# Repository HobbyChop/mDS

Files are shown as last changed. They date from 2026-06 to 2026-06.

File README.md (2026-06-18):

<table>
  <tr>
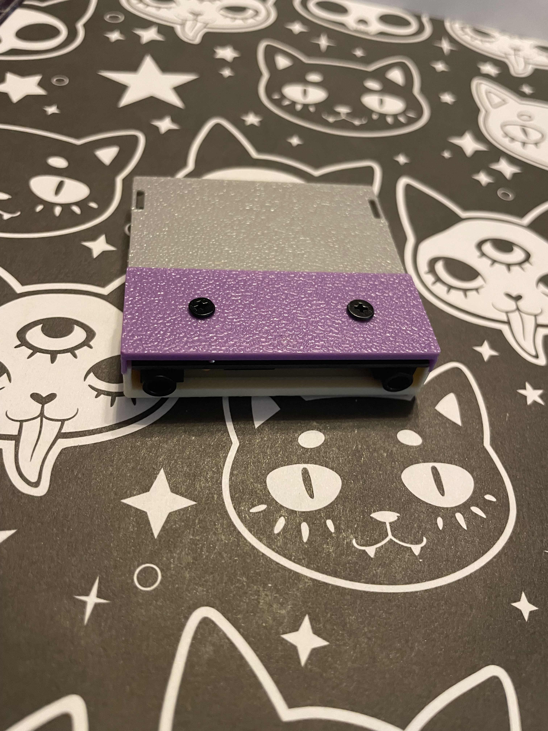
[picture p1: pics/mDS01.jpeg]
    <td align="center"><br></td>
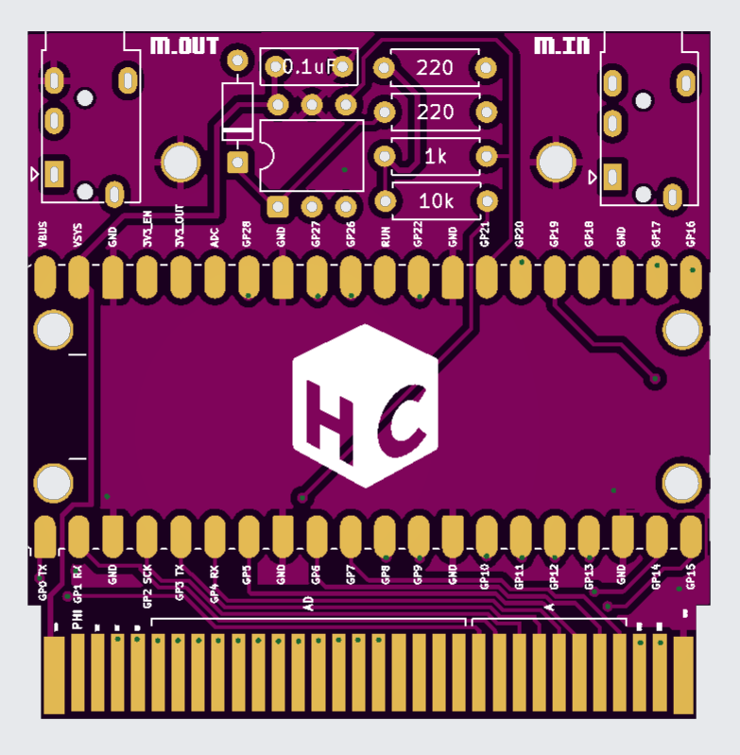
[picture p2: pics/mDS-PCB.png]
    <td align="center"><br></td>
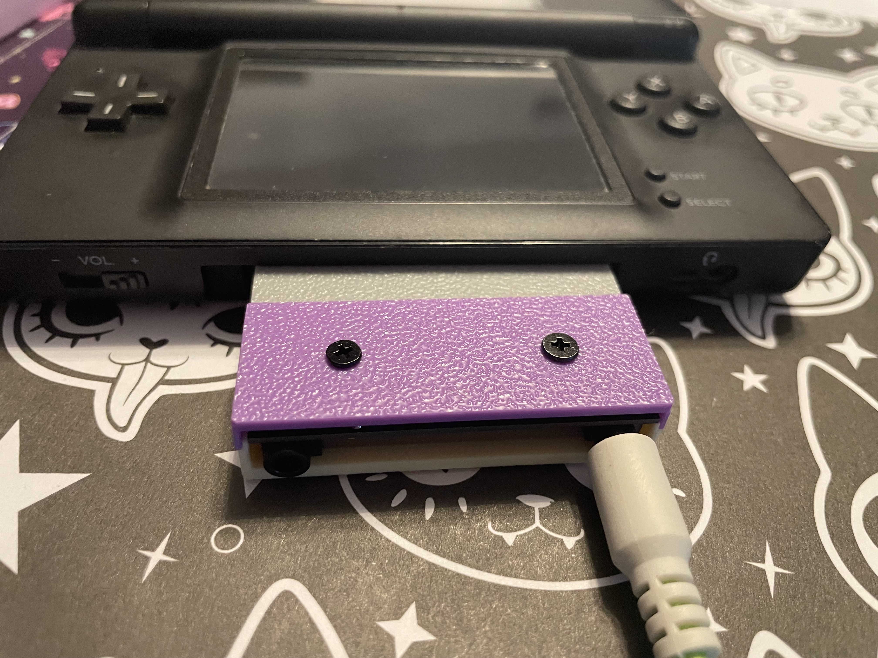
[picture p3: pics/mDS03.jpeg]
    <td align="center"><br></td>
  </tr>
</table>

# mDS - DS slot-2 MIDI cartridge

**mDS** is a Nintendo DS / DS Lite **slot-2 (GBA Game Pak) MIDI interface**
built on an RP2040. It bridges hardware MIDI into the DS over the slot-2
SRAM bus so a DS app can be a MIDI synth. The DS is the synth; the cart is
the interface - see the [sDS synth app](https://github.com/HobbyChop/sDS), the
baseline ROM that runs on it.

> One firmware, two jobs: mDS speaks the mDS `"STDS"` protocol at **version
> 2** (MIDI clock + a MIDI event ring), so the same cart drives both the
> sDS synth *and* clock-sync apps (e.g. stutter-ds) with no changes.

## Specs

| | |
|---|---|
| **MCU** | RP2040 - dual Cortex-M0+ @ 133 MHz, 264 KB SRAM (Raspberry Pi Pico module, 2 MB flash) |
| **Host interface** | GBA slot-2 SRAM region `0x0A000000`, 4 KB window (12-bit address), serviced by a PIO state machine |
| **MIDI IN** | 31250 baud UART, opto-isolated (6N138 / H11L1) |
| **MIDI OUT** | 31250 baud UART, 2x220 ohm -> TRS/DIN-5 |
| **Indicator** | onboard green LED (GPIO25): status + MIDI activity via PWM |
| **Power** | slot-2 3.3 V rail, no level shifting; 22 uF reservoir cap on VSYS |
| **Programming** | USB BOOTSEL (drag-and-drop UF2); SWD pads optional |
| **Compatibility** | DS / DS Lite only (DSi+ dropped slot-2) |

## Slot-2 bus (pin summary)

In the SRAM region the bus is **not** multiplexed: low address on A0..A11,
data returned on A16..A23 during `/RD`.

| Slot-2 signal | RP2040 GPIO | Dir | Role |
|---|---|---|---|
| A0..A7 | GPIO8..15 | in  | address low |
| A8..A11  | GPIO22, 26, 27, 28 | in  | address high (4 KB window) |
| A16..A23 | GPIO0..7 | out | data bus (driven during `/RD`) |
| /CS2 | GPIO16 | in  | SRAM chip select |
| /RD | GPIO17 | in  | read strobe |
| /WR | GPIO18 | in  | write strobe (unused) |
| /IRQ | GPIO19 | out | optional cart->DS line |
| MIDI TX  | GPIO20 | out | DIN/TRS OUT |
| MIDI RX  | GPIO21 | in  | opto IN |

## Firmware

- **core 1** runs a PIO slot-2 bus servicer (pinned to SRAM for constant-time
  serves): it answers DS reads of the SRAM window from a mirrored state struct,
  and emits MIDI OUT on trigger-reads - fixed transport at `0xE0..0xE3` plus a
  general byte sender at `0xC0..0xDF` (full notes / CC / pitch-bend / etc.).
- **core 0** parses MIDI IN (real-time clock/transport - a clock mirror;
  channel-voice notes/CC - a 16-entry event ring the DS polls) and drives
  the status LED.

### LED

| State | LED |
|---|---|
| powered, alive, no DS reading | dim slow breathe |
| a DS is linked (reading the bus) | steady glow |
| MIDI note/CC arrives | bright flash |
| MIDI clock running (transport play) | heartbeat pulse on the beat |

## Development specification

This is the most technical part of the README: how the cart works under the
hood, and how to talk to it from your own DS program. 

### How the DS and the cart talk

The cart pretends to be a small block of memory that the DS can peek at through
the Game Pak slot - picture a little **notice board**. The cart keeps the board
updated with the latest MIDI info, and the DS just keeps re-reading it.

The catch: on a real DS the slot can be **read but not reliably written**. So
the DS can look at the board, but it can't write a reply back onto it. When the
DS needs to send something *to* the cart, it instead "reads" a few special spots
on the board; the cart notices which spot was read and treats that as a command
- like buttons that do nothing except ring a bell on the cart's side (see
*Outgoing MIDI* below).

> **For programmers:** the board sits at `0x0A000000`. Open the slot with
> `gbacartOpen()` and pick the **slowest** read speed (`GBA_WAIT_SRAM_18`) so the
> cart has time to answer each read (~540 ns). Read **one byte at a time** - a
> wider read just repeats the same byte (a slot quirk). Only the first **256
> bytes** matter; reads past that wrap back to the start.

### What's on the board (layout)

An ID tag so the DS can confirm a real cart is present, some live clock and
tempo info, then a 16-slot **inbox** of recent MIDI messages. Exact layout for
coders:

| Offset | Field | Type | What it is |
|---|---|---|---|
| `0x00` | `magic` | char[4] | the tag `"STDS"` (confirms a real cart) |
| `0x04` | `version` | u8 | protocol version (`2`) |
| `0x05` | `flags` | u8 | bit0 = clock running, bit1 = transport playing |
| `0x06` | `_pad` | u8[2] | spacing |
| `0x08` | `tick_counter` | u32 | MIDI clock tick count (24 per beat) |
| `0x0C` | `bpm_q8` | u32 | tempo in BPM (fixed-point, x256) |
| `0x10` | `micros` | u32 | cart uptime in microseconds (proves it's alive) |
| `0x14` | `song_pos_16ths` | u16 | song position (in 16th notes) |
| `0x16` | `midi_write_head` | u8 | inbox: newest-slot counter (cart writes it) |
| `0x17` | `midi_read_head` | u8 | inbox: DS read position (advisory) |
| `0x18..0x57` | `midi_ring[16]` | 4B ea. | the 16-slot MIDI inbox |
| `0x58..0xFD` | `_reserved` | | unused (reads back 0) |
| `0xC0..0xE3` | doorbell addresses | | reading these sends MIDI out (see below) |

Each value is written by the cart and only read by the DS, so read one field at
a time and you always get a clean value.

### Incoming MIDI: the inbox (cart -> DS)

When MIDI arrives at the cart's IN jack, the cart drops each note or control
change into the next inbox slot and bumps a "newest" counter. The DS watches
that counter and grabs whatever it hasn't seen. The cart always finishes writing
a slot *before* bumping the counter, so the DS never catches a half-written
message. Each slot is 4 bytes:

| Byte | Meaning |
|---|---|
| 0 | message type (high half) + channel (low half) |
| 1 | first data byte (note number / CC number / ...) |
| 2 | second data byte (velocity / value / ...; 0 if unused) |
| 3 | timestamp (low byte of the clock tick) |

(Clock, start, stop, and tempo arrive separately and update the clock/tempo
fields at the top of the board, not the inbox.)

### Outgoing MIDI: the doorbell trick (DS -> cart -> OUT)

Because the DS can't write to the cart, sending MIDI *out* runs in reverse: the
DS **reads** special addresses, and the cart turns each one into a byte sent out
the MIDI OUT jack. The read returns nothing useful (just a zero) - the act of
reading *is* the message. Four addresses are hard-wired to the transport bytes,
and a range lets the DS send *any* byte:

| Read this address | What the cart does |
|---|---|
| `0xE0` / `0xE1` / `0xE2` / `0xE3` | send clock / start / stop / continue (one read each) |
| `0xC0..0xCF` | remember the high half of the next byte |
| `0xD0..0xDF` | send a byte = (that high half) + (this address's low half) |

To send any byte (notes, CC, pitch-bend, anything) the DS splits it into two
halves and reads one address for each: `0xC0 | (B>>4)` then `0xD0 | (B&0xF)`.
It's a little indirect but very fast - about 2 us per byte, far quicker than
MIDI's own wire speed, so nothing backs up. The DS-side helpers do all this for
you: `synth_cart_note_on/off/cc`, `synth_cart_midi_send`, and
`synth_cart_midi_send_byte`.

### Speed and chip layout

The Pico has two CPU cores, split cleanly: **one core does nothing but answer
the DS's reads** the instant they arrive (its code even runs from RAM so nothing
can slow it down), and **the other** handles incoming MIDI and the status light.
It runs at the stock 125 MHz - no overclock, to stay gentle on the slot's power.
MIDI is a slow 1980s standard, and the cart answers reads hundreds of times
faster than MIDI data arrives, so it never struggles to keep up.

### Limits

Great for MIDI and clock, not a channel for bulk data. The link is read-only
(the doorbell trick is the only way back), one byte per read, and 256 bytes of
shared space - plenty for MIDI (which only needs ~3 KB/s), but the hard ceiling
is around 1 MB/s, so it isn't a general-purpose data pipe.

### Writing your own DS program for it

1. Open the slot (`gbacartOpen()`) and set the slow read speed
   (`GBA_WAIT_SRAM_18`).
2. Check the ID tag: `"STDS"` at the start, version `2` right after.
3. Each frame, read the "newest" counter and pull any new inbox messages.
4. To send MIDI out, call the helper functions - and don't read the doorbell
   addresses (`0xC0..0xE3`) by accident, since reading them sends MIDI.
5. Working example: the sDS app.

## Build & flash

Uses the Raspberry Pi Pico SDK. Native (Windows) toolchain recipe:

```
cd rp2040
cmake -S . -B build -G "MinGW Makefiles" -DPICO_BOARD=pico -DPICO_SDK_PATH=C:/pico-sdk
cmake --build build -j
```

(Or `-G "Unix Makefiles"` on Linux/macOS with `PICO_SDK_PATH` exported.)
Output: **`build/mDS_v12.uf2`** (the artifact name is versioned via the target's
`OUTPUT_NAME` in `CMakeLists.txt`). Hold **BOOTSEL**, plug USB, copy the UF2
onto the `RPI-RP2` drive.

## License

Licensed under **[CC BY-NC-SA 4.0](../LICENSE)** (Attribution-NonCommercial-
ShareAlike). You may build, modify, and share your own mDS for
**non-commercial** use, with attribution and under the same license;
**selling mDS units or derivatives is not permitted**.

**Intent:** use the mDS however you like, including to make and **sell
music** (the license does not cover what you create with it). The
restriction is only on dealing in the device/design itself: no selling
mDS units or kits, no manufacturing for sale, no selling modified
firmware/hardware.

The "mDS" / "sDS" names are reserved by the author (trademark is separate
from this copyright license). For commercial use, contact the author.

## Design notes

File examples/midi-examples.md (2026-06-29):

# mDS cart -- DS-side MIDI examples

Minimal, copy-pasteable C for talking to the **mDS** slot-2 MIDI cart from a
Nintendo DS homebrew (devkitARM + libnds/calico). It covers **sending** and
**receiving** MIDI notes, CC, and clock/transport.

The cart exposes a small memory-mapped struct at the slot-2 base. Two quirks to
know up front:

1. **Read in single bytes.** The slot-2 SRAM region replicates a byte across a
   wider load, so a 32-bit read must be done as four `LDRB`s, not one `LDR`.
2. **Output is conveyed by *reads*, not writes** (the cart can't be written
   reliably). Each outgoing byte is two reads: a read of `0xC0|hi` latches the
   high nibble, then a read of `0xD0|lo` makes the cart emit `(hi<<4)|lo` on its
   UART TX.

---

## 1. Register map & low-level access

```c
#include <nds.h>
#include <calico/nds/gbacart.h>   // gbacartOpen / gbacartSetTiming

#define MDS_BASE        0x0A000000u   // slot-2 base

// offsets into the cart's mirrored sync struct
#define MDS_MAGIC       0x00          // "STDS" (4 bytes) when present
#define MDS_FLAGS       0x05          // bit1 = transport playing
#define MDS_TICK        0x08          // u32, monotonic 24-PPQ clock tick
#define MDS_BPM_Q8      0x0C          // u32, BPM in Q8.8 fixed point
#define MDS_WRITE_HEAD  0x16          // cart's ring write cursor (u8)
#define MDS_READ_HEAD   0x17          // our consume cursor (u8)
#define MDS_RING        0x18          // 16 entries x 4 bytes: status, d1, d2, tick_lo
#define MDS_RING_LEN    16
#define MDS_RING_ENTRY  4

#define MDS_TX_HI       0xC0          // read 0xC0|hi  -> latch high nibble
#define MDS_TX_LO       0xD0          // read 0xD0|lo  -> emit (hi<<4)|lo on UART

#define MDS_FLAG_PLAY   (1u << 1)

// A single-byte read is correct; only wide loads hit the replication quirk.
static inline u8 mds_rd8(u32 off) {
    return *(volatile u8 *)(MDS_BASE + off);
}

// 32-bit read as four explicit LDRBs (so the compiler can't fold them to one LDR).
static u32 mds_rd32(u32 off) {
    u32 base = MDS_BASE + off, b0, b1, b2, b3;
    __asm__ __volatile__(
        "ldrb %0,[%4,#0]\n ldrb %1,[%4,#1]\n ldrb %2,[%4,#2]\n ldrb %3,[%4,#3]\n"
        : "=&l"(b0), "=&l"(b1), "=&l"(b2), "=&l"(b3) : "l"(base) : "memory");
    return b0 | (b1 << 8) | (b2 << 16) | (b3 << 24);
}
```

---

## 2. Detect / open the cart

```c
static int   s_active   = 0;
static u8    s_read_head = 0;

// Open slot-2, set timing, and verify the cart magic. Safe to call again to
// re-probe. Returns true if an mDS cart is present.
bool mds_open(void) {
    if (!gbacartOpen()) { s_active = 0; return false; }   // claim slot-2 + MPU
    gbacartSetTiming(GBA_WAIT_SRAM_MASK, GBA_WAIT_SRAM_18);

    // The open/timing hand-off is async, so retry the magic read a few times.
    for (int i = 0; i < 16; ++i) {
        if (mds_rd8(MDS_MAGIC+0)=='S' && mds_rd8(MDS_MAGIC+1)=='T' &&
            mds_rd8(MDS_MAGIC+2)=='D' && mds_rd8(MDS_MAGIC+3)=='S') {
            s_active    = 1;
            s_read_head = mds_rd8(MDS_WRITE_HEAD) % MDS_RING_LEN;   // start synced
            return true;
        }
        swiDelay(2000);
    }
    gbacartClose();
    s_active = 0;
    return false;
}

bool mds_present(void) { return s_active != 0; }
```

> Tip: don't touch slot-2 before `mds_open()` -- a raw read on some flashcarts
> before the cart is claimed can wedge them. Probe a couple of frames into boot.

---

## 3. Send MIDI OUT (notes, CC, raw bytes)

```c
// One raw byte out (use this for realtime bytes: clock 0xF8, start 0xFA, stop 0xFC).
void mds_send_byte(u8 b) {
    if (!s_active) return;
    (void)mds_rd8((u32)MDS_TX_HI | (u32)(b >> 4));     // latch high nibble
    (void)mds_rd8((u32)MDS_TX_LO | (u32)(b & 0x0F));   // low nibble -> cart emits b
}

// One channel-voice message (status 0x80..0xEF).
void mds_send(u8 status, u8 d1, u8 d2) {
    if (!s_active || status < 0x80 || status >= 0xF0) return;
    mds_send_byte(status);
    mds_send_byte(d1 & 0x7F);
    mds_send_byte(d2 & 0x7F);
}

static inline void mds_note_on (u8 ch, u8 note, u8 vel) { mds_send(0x90 | (ch & 0xF), note, vel); }
static inline void mds_note_off(u8 ch, u8 note, u8 vel) { mds_send(0x80 | (ch & 0xF), note, vel); }
static inline void mds_cc      (u8 ch, u8 num,  u8 val) { mds_send(0xB0 | (ch & 0xF), num,  val); }

// Example: play middle C on channel 1 for one beat, then release.
void example_play_note(void) {
    mds_note_on(0, 60, 100);     // ch 1 (0-based), note 60, velocity 100
    // ... hold for a beat ...
    mds_note_off(0, 60, 0);
}
```

---

## 4. Receive MIDI IN (drain the event ring)

External gear -> cart UART RX -> 16-entry ring -> your DS. Drain it every frame.

```c
// Pop one received channel-voice event. Returns true and fills out-params when
// one was waiting; false when the ring is drained. Skips torn/empty slots.
bool mds_recv(u8 *status, u8 *d1, u8 *d2) {
    if (!s_active) return false;
    u8 wh = mds_rd8(MDS_WRITE_HEAD) % MDS_RING_LEN;
    int guard = 0;
    while (s_read_head != wh && guard++ < MDS_RING_LEN) {
        u32 e = MDS_RING + (u32)s_read_head * MDS_RING_ENTRY;
        u8 s = mds_rd8(e+0), a = mds_rd8(e+1), b = mds_rd8(e+2);   // [3] = tick_lo
        s_read_head = (s_read_head + 1) % MDS_RING_LEN;
        if (s & 0x80) {                  // valid status byte = a real event
            if (status) *status = s;
            if (d1) *d1 = a;
            if (d2) *d2 = b;
            return true;
        }
    }
    return false;
}

// Example: consume everything received this frame.
void example_read_input(void) {
    u8 st, d1, d2;
    while (mds_recv(&st, &d1, &d2)) {
        u8 type = st & 0xF0, ch = st & 0x0F;
        if      (type == 0x90 && d2 > 0) { /* note on : note=d1 vel=d2 ch=ch */ }
        else if (type == 0x80 || (type == 0x90 && d2 == 0)) { /* note off */ }
        else if (type == 0xB0) { /* control change: cc=d1 val=d2 */ }
    }
}
```

---

## 5. Clock & transport

### Reading an incoming clock (slave)

```c
int  mds_bpm(void) {                          // 0 if no clock
    if (!s_active) return 0;
    u32 q8 = mds_rd32(MDS_BPM_Q8);
    if (q8 < (20u<<8) || q8 > (300u<<8)) return 0;   // sanity gate
    return (int)((q8 + 128u) >> 8);                  // Q8 -> nearest BPM
}

u32  mds_tick(void) { return s_active ? mds_rd32(MDS_TICK) : 0; }   // 24 PPQ
bool mds_playing(void) { return s_active && (mds_rd8(MDS_FLAGS) & MDS_FLAG_PLAY); }

// Example: derive bar/beat and step a 16-step sequencer off the incoming clock.
// The tick is monotonic 24-PPQ; the host zeroes it on transport Start.
void example_follow_clock(void) {
    if (!mds_playing()) return;
    u32 t    = mds_tick();
    int beat = (t / 24) % 4;           // 24 ticks per quarter note
    int step = (t / 6) % 16;           // 6 ticks = 1/16 note -> 16 steps/bar
    (void)beat; (void)step;            // fire your step here when it changes
}
```

### Being the master (send clock out)

MIDI clock is 24 pulses per quarter note. **For tight timing, drive this from a
hardware-timer IRQ** (≈1–2 kHz) rather than the 60 Hz VBlank loop -- emitting one
F8 per frame bunches pulses on frame boundaries (up to ~16 ms jitter).

```c
// Call at your tick cadence (ideally a timer ISR). Sends 24 F8 per quarter.
void mds_clock_pulse(void) { mds_send_byte(0xF8); }   // realtime clock
void mds_transport_start(void) { mds_send_byte(0xFA); }   // slaves reset to bar 1 + run
void mds_transport_stop (void) { mds_send_byte(0xFC); }   // slaves halt

// Phase-accumulator example for a VBlank-loop master (carries the remainder so
// there's no long-term drift; jitter is frame-granular -- use a timer for tight).
static int s_acc = 0;
void example_emit_clock_per_frame(int bpm) {   // call once per 60 Hz frame
    s_acc += bpm;                               // 1 quarter = 3600 units @ 60fps
    while (s_acc >= 150) { mds_clock_pulse(); s_acc -= 150; }   // 3600/24 = 150
}
```

---

## 6. Putting it together (per-frame skeleton)

```c
int main(void) {
    // ... video / audio init ...
    if (!mds_open()) { /* show "no mDS cart" */ }

    while (1) {
        swiWaitForVBlank();
        scanKeys();

        // INPUT: consume incoming notes/CC/clock
        example_read_input();
        if (mds_playing()) example_follow_clock();

        // OUTPUT: e.g. a pad press sends a note
        if (keysDown() & KEY_A) mds_note_on(0, 60, 100);
        if (keysUp()   & KEY_A) mds_note_off(0, 60, 0);
    }
}
```

---

### Notes
- Channels are 0-based on the wire (`ch & 0x0F`); MIDI "channel 1" = `0`.
- `mds_recv()` consumes the ring -- if you only want clock/BPM for a readout and
  aren't reading notes, keep the read cursor synced instead (`s_read_head =
  mds_rd8(MDS_WRITE_HEAD) % MDS_RING_LEN;` each frame) so the ring never appears
  full to the cart.
- Velocity-0 note-on is the conventional note-off; handle both.
- All reads are cheap (a couple of `LDRB`s); a full message out is 6 reads.

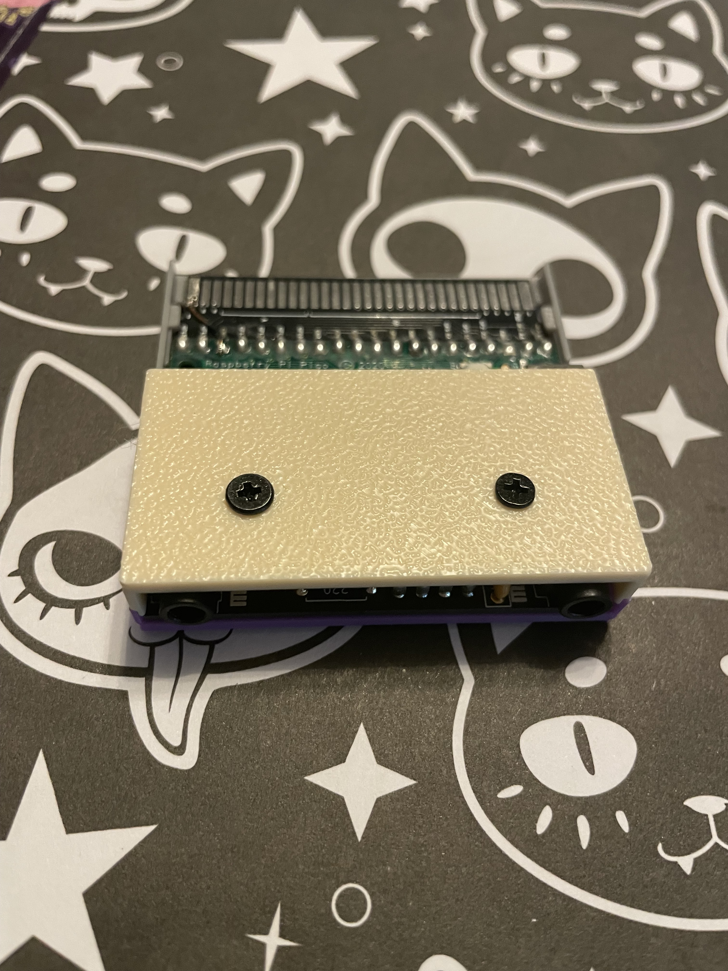
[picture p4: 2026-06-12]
pics/mDS02.jpeg

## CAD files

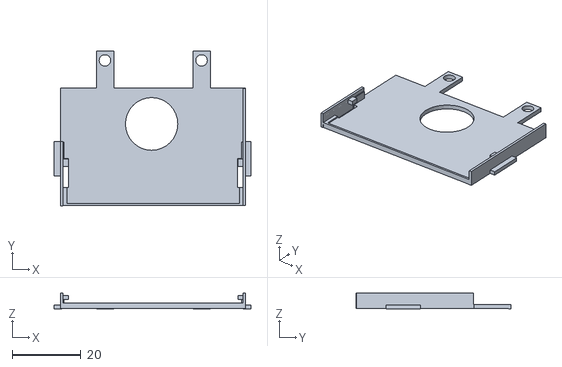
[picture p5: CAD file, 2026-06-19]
build/shell/ds-slot2-midi.stl
57.3 x 45.0 x 4.52

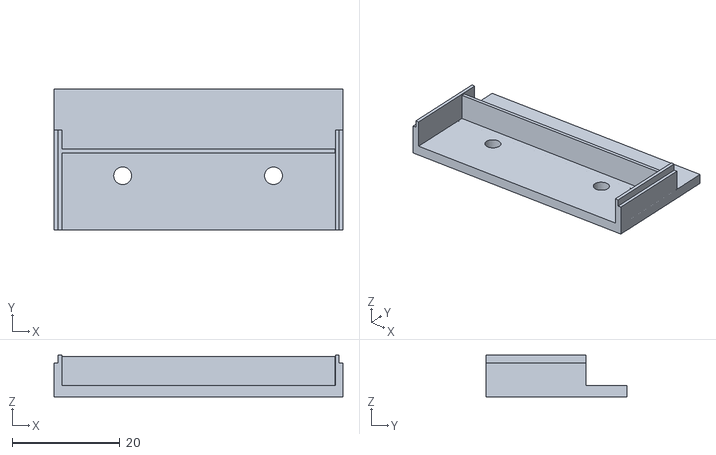
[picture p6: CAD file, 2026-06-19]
build/shell/mds-slot2-midi-top.stl
53.8 x 26.2 x 7.80

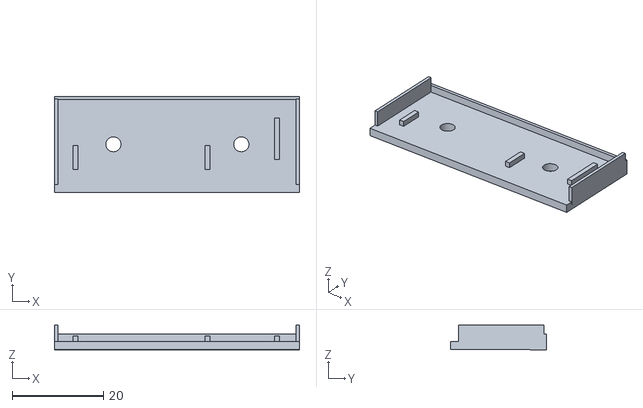
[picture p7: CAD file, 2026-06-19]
build/shell/ds-slot2-midi-btm-piece2.stl
53.8 x 21.1 x 5.38

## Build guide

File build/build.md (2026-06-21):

How to build your own mDS slot-2 MIDI cartridge: parts, assembly, and
flashing.

## Bill of materials

### Electronics

| Qty | Part | Notes |
|----:|---|---|
| 1 | Raspberry Pi Pico (RP2040) | Not RP2040-Zero. |
| 1 | mDS PCB | Important! 1mm thickess, ENIG
| 1 | H11L1 optocoupler | MIDI IN isolation  |
| 1 | 1N4148 diode | MIDI IN reverse protection  |
| 2 | 220 Ω resistor | MIDI line resistors  |
| 1 | 1 kΩ resistor | H11L1 output pull-up. |
| 1 | 10 kΩ resistor | pull-up |
| 2 | 100 nF ceramic capacitor | decoupling  |
| 2 | PJ-320E 3.5 mm jack | MIDI IN + MIDI OUT (TRS-MIDI). |

The status indicator is the Pico's onboard green LED (GPIO25): no extra part.

### Fasteners and mechanical

| Qty | Part |
|----:|---|
| 4 | M2.5 x 6 mm screws |
| 2 | M2.5 x 6 mm standoffs (Brass is best)|
| 1 set | 3D-printed shell pieces (3) |

**Shell:** print from the STL files for the shell pieces.

## Tools

Soldering iron + solder, flux, side cutters, a small Phillips driver for
the M2.5 hardware, and a USB cable (data, not charge-only) for flashing.

## Assembly

1. **Front-end:** solder the H11L1 and its 1N4148, the 220 Ω / 1 kΩ / 10 kΩ
   resistors, and the 100 nF decoupling; fit the two
   PJ-320E jacks. Exact placement follows the PCB silkscreen / schematic.

**Important!** Don't socket the H11L1 or it will be too tall for the shell.

**Important!** Clip the bottom of the pins as flush as possible to the board, so the shell pieces will fit.
   
3. **Pico:** mount the Pico to the PCB (solder no header). 
4. **Mechanical:** fit the board into the printed shell using the standoffs
   and screws as the shell design dictates.
   
**Important!** Do NOT plug in a usb cable while the cartridge is inserted into your DS. USB is for flashing firmware only!
   
5. **Flash + test**

## Flash the firmware

Build `mDS.uf2`
then hold **BOOTSEL**, plug USB, and copy the UF2 onto the `RPI-RP2` drive.
On a USB serial monitor you should see the banner
`sDS synth cart fw ... STDS protocol v2` and the green LED begin its slow
"alive" breathe.

## License

Build-your-own is welcome for non-commercial (resell) use, with attribution and
share-alike, under [CC BY-NC-SA 4.0](../LICENSE). Selling mDS units or
derivatives is not permitted; the "mDS" / "sDS" names are reserved.

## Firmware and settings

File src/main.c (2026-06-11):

/**
 * RP2040 Slot-2 MIDI Cartridge Firmware -- sDS synth cart ("STDS" v2).
 *
 * Speaks the mDS "STDS" protocol at version 2 (clock + MIDI event ring),
 * so ONE flashed firmware serves both stutter-ds clock sync and the sDS
 * MIDI synth -- see sync_state.h.
 *
 * Role: a memory-mapped MIDI I/O bridge the DS reads from. This is the
 * interface half of an mGB-style setup -- the DS ROM is the synthesizer
 * (pulse / sample / noise / FM voices on native DS audio); the cart
 * just gets MIDI in and out of the DS. The Pico's job is to:
 *   - Receive MIDI bytes on UART1 RX (GPIO21) at 31250 baud.
 *   - Parse real-time messages (0xF8 clock / 0xFA start / 0xFC stop /
 *     0xF2 SPP) into the clock/transport mirror, AND channel-voice
 *     messages (note on/off, CC, pitch-bend, ...) into the event ring.
 *   - Serve DS reads of the SRAM window at 0x0A000000 from that mirror.
 *   - Emit MIDI OUT bytes on UART1 TX when the DS does a trigger-read
 *     at 0xE0..0xE3 (see bus_pio.c midi_tx_dispatch).
 *
 * Core split:
 *   core 0 -- MIDI UART RX/parse + sync_state updates + USB debug
 *   core 1 -- tight PIO loop servicing the GBA bus + MIDI TX triggers
 *
 * The DS side is in `ds-rom/source/synth_cart.c`; the shared layout
 * lives in `sync_state.h` and the DS driver's `midi_sync_state_t`.
 * Keep them byte-for-byte aligned.
 *
 * Status / known limits:
 *   - DS->cart commands use read-trigger side effects (slot-2 SRAM
 *     /WR is unreliable across DS variants); only 0xE0..0xE3 MIDI OUT
 *     triggers are wired so far.
 */

#include <stdio.h>
#include "pico/stdlib.h"
#include "pico/stdio_usb.h"
#include "pico/multicore.h"
#include "pico/time.h"
#include "hardware/gpio.h"

#include "bus_interface.h"
#include "bus_pio.h"
#include "midi.h"
#include "sync_state.h"
#include "led.h"

// USB-CDC stdio is convenient for development -- prints status,
// MIDI byte counts, etc. Disable for final builds to save flash
// + boot time.
#define WITH_DEBUG_STDIO  1

void core1_main(void) {
    // Bus-servicing core. PIO state machine catches /CS2 + /RD edges
    // with sub-clock-cycle precision; this core just drains addresses
    // from the RX FIFO, looks up bytes, and pushes responses. No
    // allocation, no logging.
    while (1) {
        bus_pio_service_blocking();
    }
}

int main(void) {
#if WITH_DEBUG_STDIO
    // CMakeLists.txt sets PICO_STDIO_USB_CONNECT_WAIT_TIMEOUT_MS so
    // this call blocks until the USB CDC host opens the port (or 3 s
    // timeout). That makes the banner + tracer prints below reliably
    // visible during bringup instead of racing with Windows CDC
    // enumeration.
    stdio_init_all();
#endif

    // Tracer prints between init steps -- if any of these ever hangs
    // or crashes in the future, the last printed message tells us
    // which step died. Cheap insurance, runs only on debug builds.
#if WITH_DEBUG_STDIO
    printf("init: sync_state\n");
#endif
    sync_state_init();
#if WITH_DEBUG_STDIO
    printf("init: sync_state ok\n");
    printf("init: bus_pio\n");
#endif
    bus_pio_init();
#if WITH_DEBUG_STDIO
    printf("init: bus_pio ok\n");
    printf("init: midi\n");
#endif
    midi_init();
    led_init();   // onboard green LED (GPIO25): status + MIDI activity
#if WITH_DEBUG_STDIO
    printf("init: midi ok\n");
    printf("sDS synth cart fw v0.1 -- STDS protocol v%u\n",
           (unsigned)SYNC_PROTOCOL_VERSION);
#endif

    // Hand the bus interface to core 1 so MIDI parsing on core 0
    // never starves it. Each core has its own stack.
    multicore_launch_core1(core1_main);

    // Core 0: MIDI poll. The UART has its own FIFO and we drain it
    // each iteration; the real-time clock-tick path updates
    // sync_state without further locking.
    //
    // 1 Hz heartbeat: time_reached() / make_timeout_time_ms() avoid
    // a sleep, so MIDI byte latency stays sub-ms. The line carries
    // uptime (= core 0 isn't wedged) plus the live sync_state fields
    // (= MIDI parse state once the input is wired up). Bus servicer
    // on core 1 doesn't pay anything for this; the slot-2 timing
    // budget is unchanged.
#if WITH_DEBUG_STDIO
    absolute_time_t next_beat = make_timeout_time_ms(1000);
#endif
    while (1) {
        midi_poll_input();
        led_task();   // status + MIDI-activity on the onboard LED (self-throttled)
#if WITH_DEBUG_STDIO
        // Gate the heartbeat printf on USB-host-connected. When the
        // host (= PlatformIO monitor) ISN'T draining the CDC FIFO,
        // printf blocks for tens of ms waiting for the FIFO to free
        // up -- and during that block midi_poll_input() can't drain
        // the UART RX FIFO, so MIDI byte handling (including the
        // 0xFA START byte that triggers transport-rise) is delayed
        // unpredictably. That delay is a major contributor to
        // randomized DS-side start alignment with the DAW. With
        // this gate, headless runs (DS-only, no PC) skip the
        // heartbeat entirely and the MIDI poll loop stays tight;
        // debug runs (monitor open) still see heartbeat as before.
        if (time_reached(next_beat) && stdio_usb_connected()) {
            next_beat = make_timeout_time_ms(1000);
            sync_state_t *s = sync_state_get();
            bus_stats_t bs;
            bus_get_stats(&bs);
            printf("alive uptime=%u ms | midi rx=%u tick=%u bpm_q8=%u flags=0x%02x"
                   " | bus cs2=%u rd=%u wr=%u"
                   " addr_cs2=0x%04x addr_rd=0x%04x or=0x%04x last=0x%02x\n",
                   (unsigned)to_ms_since_boot(get_absolute_time()),
                   (unsigned)midi_rx_byte_count(),
                   (unsigned)s->tick_counter,
                   (unsigned)s->bpm_q8,
                   (unsigned)s->flags,
                   (unsigned)bs.cs2_active_edges,
                   (unsigned)bs.reads_served,
                   (unsigned)bs.writes_seen,
                   (unsigned)bs.last_address,
                   (unsigned)bs.last_address_at_rd,
                   (unsigned)bs.address_or,
                   (unsigned)bs.last_byte_served);
        } else if (time_reached(next_beat)) {
            // Re-arm the timer even when we skipped, so reconnecting
            // the monitor mid-session doesn't dump a stale 1-second
            // backlog and resumes 1 Hz from then on.
            next_beat = make_timeout_time_ms(1000);
        }
#endif
    }
    return 0;
}

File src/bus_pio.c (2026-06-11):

/**
 * PIO-driven slot-2 bus servicer -- implementation.
 *
 * See bus.pio for the state-machine assembly and protocol notes.
 * This file wires the program onto PIO0 SM0 and runs the CPU-side
 * lookup loop.
 *
 * Stats are exposed via bus_get_stats() (declared in bus_interface.h)
 * so the existing heartbeat in main.c keeps working without changes.
 * We override the polled implementation's storage by giving bus_pio.c
 * its own counter set and a bus_get_stats() override.
 */

#include "bus_pio.h"
#include "bus_interface.h"
#include "sync_state.h"
#include "midi.h"

#include "hardware/pio.h"
#include "hardware/gpio.h"
#include "hardware/uart.h"
#include "hardware/structs/sio.h"
#include "hardware/structs/pads_bank0.h"

#include "bus.pio.h"   // generated by pico_generate_pio_header()

// NEW SRAM-cart wiring (post-bringup, May 2026):
//   GP0..GP7   -> slot-2 pins 22..29 (A16..A23 = data D0..D7)
//   GP8..GP15  -> slot-2 pins 6..13  (A0..A7 = low address bits)
//   GP22,26,27,28 -> slot-2 pins A8..A11 (address high bits, sampled by CPU)
//   GP16       -> /CS2
//   GP17       -> /RD
// (GP18 = /WR, GP19 = /REQ, GP20/21 = MIDI -- not used by the PIO)
#define DATA_BASE   0       // GP0..GP7 = A16..A23 (cart-driven data)
#define DATA_COUNT  8
#define ADDR_BASE   8       // GP8..GP15 = A0..A7 (DS-driven low address bits)
#define ADDR_BITS   8       // low 8 address bits
#define ADDR_HIGH_A8_PIN   22
#define ADDR_HIGH_A9_PIN   26
#define ADDR_HIGH_A10_PIN  27
#define ADDR_HIGH_A11_PIN  28
#define ADDR_HIGH_BITS     4 // A8..A11 (address high nibble, sampled by CPU)
#define CS2_PIN     16
#define RD_PIN      17
#define WR_PIN      18      // unused by PIO; init below sets it to input + pull-up
#define IRQ_PIN     19      // unused by PIO; init below leaves it driven low

static PIO  s_pio = pio0;
static uint s_sm  = 0;
static uint s_offset = 0;

// Cached pointer to the live sync_state byte mirror -- captured at
// bus_pio_init() time so the per-cycle CPU work in core 1 is a
// single byte load instead of a function call + load. core 0's
// MIDI parser updates the underlying struct asynchronously.
static const uint8_t *s_sync_bytes = NULL;

// Diagnostic counters. Same fields as bus_interface.c's so the
// heartbeat format string in main.c doesn't have to change.
static volatile uint32_t s_cs2_edges        = 0;
static volatile uint32_t s_reads_served     = 0;
static volatile uint32_t s_writes_seen      = 0;   // PIO path doesn't handle writes
static volatile uint32_t s_last_address     = 0;
static volatile uint32_t s_last_address_rd  = 0;
static volatile uint32_t s_address_or       = 0;
static volatile uint16_t s_ad_pins_or       = 0;
static volatile uint8_t  s_last_byte_served = 0;

void bus_get_stats(bus_stats_t *out) {
    if (!out) return;
    out->cs2_active_edges   = s_cs2_edges;
    out->reads_served       = s_reads_served;
    out->writes_seen        = s_writes_seen;
    out->last_address       = s_last_address;
    out->last_address_at_rd = s_last_address_rd;
    out->address_or         = s_address_or;
    out->ad_pins_or         = s_ad_pins_or;
    out->last_byte_served   = s_last_byte_served;
}

bool bus_pio_init(void) {
    // Load the program into PIO0's instruction memory.
    s_offset = pio_add_program(s_pio, &slot2_bus_program);

    // Configure all PIO-driven pins. pio_gpio_init sets the GPIO
    // function to PIO0 so the state machine can drive/sample them.
    // - GP0..GP7  (data, driven by us)
    // - GP8..GP15 (address bits, sampled from DS; low 8 bits)
    // - GP16, GP17 (/CS2, /RD, sampled from DS)
    for (uint i = 0; i < DATA_COUNT; i++) {
        pio_gpio_init(s_pio, DATA_BASE + i);
    }
    for (uint i = 0; i < ADDR_BITS; i++) {
        pio_gpio_init(s_pio, ADDR_BASE + i);
    }
    gpio_init(ADDR_HIGH_A8_PIN);  gpio_set_dir(ADDR_HIGH_A8_PIN,  GPIO_IN); gpio_pull_down(ADDR_HIGH_A8_PIN);
    gpio_init(ADDR_HIGH_A9_PIN);  gpio_set_dir(ADDR_HIGH_A9_PIN,  GPIO_IN); gpio_pull_down(ADDR_HIGH_A9_PIN);
    gpio_init(ADDR_HIGH_A10_PIN); gpio_set_dir(ADDR_HIGH_A10_PIN, GPIO_IN); gpio_pull_down(ADDR_HIGH_A10_PIN);
    gpio_init(ADDR_HIGH_A11_PIN); gpio_set_dir(ADDR_HIGH_A11_PIN, GPIO_IN); gpio_pull_down(ADDR_HIGH_A11_PIN);
    pio_gpio_init(s_pio, CS2_PIN);
    pio_gpio_init(s_pio, RD_PIN);

    // Direction defaults: data pins as inputs (the program flips to
    // output during the /RD low window, then back). Address pins
    // ALWAYS inputs (DS drives them). /CS2 and /RD always inputs.
    pio_sm_set_consecutive_pindirs(s_pio, s_sm, DATA_BASE, DATA_COUNT, false);
    pio_sm_set_consecutive_pindirs(s_pio, s_sm, ADDR_BASE, ADDR_BITS,  false);
    pio_sm_set_consecutive_pindirs(s_pio, s_sm, CS2_PIN,   1, false);
    pio_sm_set_consecutive_pindirs(s_pio, s_sm, RD_PIN,    1, false);

    // Build the SM config from the program defaults, then patch in
    // our pin assignments.
    pio_sm_config c = slot2_bus_program_get_default_config(s_offset);

    // `in pins, 8` reads the low address byte from GP8..GP15, so the
    // input base is GP8 (= ADDR_BASE). The upper address bits A8..A11
    // are sampled separately by the CPU from dedicated GPIO pins.
    // `out pins, 16` writes 16 bits starting at GP0 (= DATA_BASE) --
    // only the low 8 of those are actually driven thanks to the 0x00FF
    // pindir mask, but the OUT instruction still ticks through all 16
    // to cleanly clear the OSR for the pindir write that follows.
    sm_config_set_in_pins (&c, ADDR_BASE);
    sm_config_set_out_pins(&c, DATA_BASE, 16);

    // Run at full system clock (125 MHz). Each PIO instruction is
    // 8 ns, so wait-edge-to-sample is ~8 ns -- well inside the
    // cart's address window.
    sm_config_set_clkdiv(&c, 1.0f);

    // ISR config: shift LEFT so each `in pins, 4` lands the 4
    // sampled bits in ISR's low 4 positions (the next `in` would
    // shift the previous bits up and add new ones at the bottom).
    // Push then puts a 32-bit word into RX FIFO whose low nibble
    // is the address; CPU does `addr & 0xF` to extract.
    // (Shift-right would land them at bits 28..31, requiring the
    // CPU to do `addr >> 28` -- functionally equivalent but more
    // confusing to read.)
    // Auto-push off; we use explicit `push` in the PIO program.
    sm_config_set_in_shift (&c, false /*shift left*/, false /*no auto-push*/, 32);
    // OSR shifts out from LSB. CPU packs a 32-bit word into TX FIFO:
    //   bits 0..15  -> data (out pins, 16)   -- low 8 = the response byte
    //   bits 16..31 -> pindir mask (out pindirs, 16) -- 0x00FF
    sm_config_set_out_shift(&c, true /*shift right*/, false /*manual pull*/, 32);

    pio_sm_init(s_pio, s_sm, s_offset, &c);

    // Disable internal pulls on data pins -- they're driven (either
    // by us or by the DS), and weak pulls would fight the active
    // driver during transitions.
    for (uint i = 0; i < DATA_COUNT; i++) gpio_disable_pulls(DATA_BASE + i);
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

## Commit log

2026-06-11 Simplify assembly instructions in build.md
    Removed references to GPIO mapping and shell closure notes for clarity.
2026-06-11 Remove protocol layout reference from README
    Removed reference to protocol layout and slot-2 conventions.
2026-06-12 Update mDS PCB notes in build.md
2026-06-21 Update build instructions with important assembly notes
    Added important notes on socketing and pin clipping for assembly.
